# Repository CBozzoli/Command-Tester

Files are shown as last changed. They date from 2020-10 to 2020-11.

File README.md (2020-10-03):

# Command-Tester
Arduino Pro Mini Sketch for the Sacramento Astromech Builders Command Tester

Overview:

The purpose of the Command Tester board is to allow a user to send commands to various devices for testing purposes without having to install those devices into an existing system first.  This makes benchtop testing much easier.

The tester can be powered with a 7-36V input to the onboard Pololu D24V50F5 regulator which will give a constant 5V output at 5A to power the connected devices over the Serial or I2C bus.  There is also a +5V output header to power additional devices if needed.  Alternately, this header can be used to feed a regulated 5V input to the board if the user does not wish to install the Pololu regulator.

The Command Tester supports sending commands via I2C as well as Serial. Under normal usage, the command tester does not need to receive I2C commands, however there is receive code in the basic sketch, so it is possible to send I2C commands to the tester if the user wishes it. See the Code section below for more information on this. At this time, the tester does not receive Serial commands.

Board Versions:

There are currently 3 versions of the Command Tester board.  The differences between the boards are:

•	The v1 board has 15 command buttons, while v1.1 and v1.2 have 14. The reason for this is because Digital pin 13 is connected to the LED on the Arduino Pro Mini and should not be used as an input, therefore it was removed in the later versions. If you are using a v1 board, you should skip the CMD 12 button when assembling (this means that CMD 13- 15 are actually CMD 12-14). The code already takes this into account.

•	The location of the Shift Switch and LED is different on each version of the board.
Other than the above, the boards are functionally equivalent.

The Arduino Pins are assigned as follows:

•	TX0		Serial Transmit

•	RXI		Serial Receive

•	D2		Command 1

•	D3		Command 2

•	D4		Command 3

•	D5		Command 4

•	D6		Command 5

•	D7		Command 6

•	D8		Command 7

•	D9		Command 8

•	D10		Command 9

•	D11		Command 10

•	D12		Command 11

•	D13		Pro Mini On Board LED

•	A0/D14	Command 12

•	A1/D15	Command 13

•	A2/D16	Command 14

•	A3/D17	Shift

•	A4/D18	SDA (I2C)

•	A5/D19	SCL (I2C)		

Code:

The current version of the Command Tester code consists of two files that must be placed in the same directory:

•	Command_Tester_Skeleton_1.1.ino (the main sketch)

•	config.h (header file that includes configuration settings)

The sketch is distributed as a “skeleton” to allow users to insert the commands needed for the devices they are testing.  This is done by typing the commands into the arrays on the config.h tab.  Notes on how to do this are in the sketch.

There are several user configurable settings in the config header:

•	Commands

•	BAUD Rate (Default is 2400 for Teeces compatibility, 9600 and 57600 are also available for JEDI and Stealth compatibility)

•	I2C Address of the Tester (default is 0)

•	I2C Addresses for receive devices

•	Debug Toggle (turns on/off debug messages, default is on)

•	I2C Receive Mode (see below for more on this)

The default behavior of the Command Tester is as the I2C bus master and does not need to receive I2C commands; however, the receive code is included in case a scenario arises where it is needed. The receive command function is different depending on what device is sending the I2C commands. For example, the Stealth Controller sends integer I2C commands only, but the Marcduino sends commands as character strings. To deal with this, a software switch called SIMPLE_I2C is included to determine the I2C Receive Mode. If the device sending the commands to the tester is something like the Stealth Controller, then turn on Simple receive by uncommenting this line in the config header. If it is something like the Marcduino, then use the complex receive. A general rule of thumb to help you determine which to use is how you enter the commands in the sketch that is sending them. If you must put the command in quotes (e.g. “10\r”), then use complex. If you do not use quotes (e.g. 10), use simple. The default setting is complex.

Warning:  If you do find a need for the tester to receive commands, you may need to do additional coding to accomplish what you need as neither mode will parse JAWALITE commands (both simple and complex modes only handle numerical commands).

Bill of Materials:

•	1x Arduino Pro Mini 5V, 16 MHz

•	1x Pololu D24V50F5 5v, 5A Step-Down Regulator (https://www.pololu.com/product/2851)

•	Various Male and Female Pin Headers

•	14x Momentary Tactile Button Switch (Digikey Part Number 1528-367-ND, https://www.digikey.com/products/en?mpart=367&v=1528)

•	1x 5mm LED

•	1x 1k Ohm Resistor

•	1x Screw Terminal Block (2-Pin, 5 mm Pitch, Side Entry, https://www.pololu.com/product/2440)

•	1x 6-pin, 2.54mm Pitch, Self-Latching Switch (I don’t have a part number for these. I purchased them from Amazon.com in a variety pack and used the 8x8mm ones. If you buy these, you should probably test the switch before soldering it on to make sure the pin configuration is correct. https://www.amazon.com/gp/product/B07J4ZCWNX/ref=ppx_yo_dt_b_asin_title_o03_s00?ie=UTF8&psc=1).
 
Images can be found in the Wiki verion of this file here: https://github.com/CBozzoli/Command-Tester/wiki

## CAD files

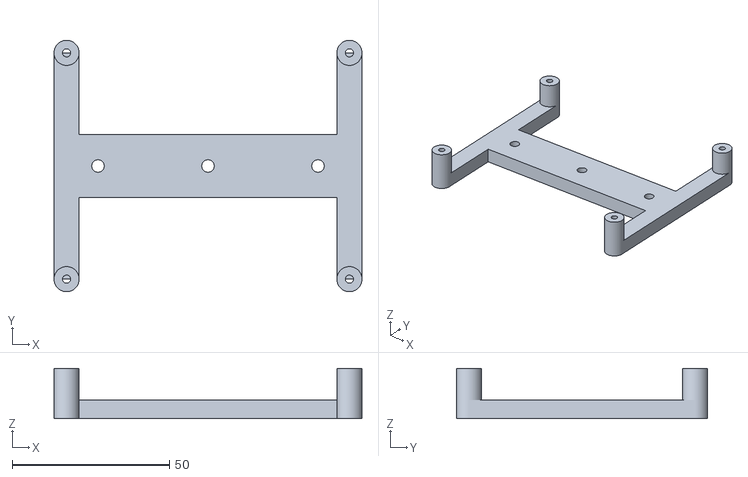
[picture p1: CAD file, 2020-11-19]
Command_Tester_Base.stl
98.0 x 80.0 x 16.0

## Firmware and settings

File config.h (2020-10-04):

// SacAstromech Command Tester v1.1
// Configuration Header

// Place the name of the command set here.  This is used for Debug lines.
// (e.g. "PSI Pro Commands")

#define COMMAND_SET "Test Command Set"

// Enter Command strings here.
// Place the command between the quote marks.
// Format is dependent on the devices you are using
// (e.g. 0T1|10\r for a JAWALITE formatted PSI Pro command with a time modifier)

//Array for Commands 1-14
char *CMD[] {
"" ,     // CMD 1 
"" ,     // CMD 2 
"" ,     // CMD 3 
"" ,     // CMD 4 
"" ,     // CMD 5 
"" ,     // CMD 6 
"" ,     // CMD 7 
"" ,     // CMD 8 
"" ,     // CMD 9 
"" ,     // CMD 10 
"" ,     // CMD 11 
"" ,     // CMD 12 
"" ,     // CMD 13 
"" ,     // CMD 14 
};

//Array for Commands 15-28
char *SHIFT_CMD[] {
"" ,     // SHIFT/CMD 1 
"" ,     // SHIFT/CMD 2 
"" ,     // SHIFT/CMD 3 
"" ,     // SHIFT/CMD 4 
"" ,     // SHIFT/CMD 5 
"" ,     // SHIFT/CMD 6 
"" ,     // SHIFT/CMD 7 
"" ,     // SHIFT/CMD 8 
"" ,     // SHIFT/CMD 9 
"" ,     // SHIFT/CMD 10 
"" ,     // SHIFT/CMD 11 
"" ,     // SHIFT/CMD 12
"" ,     // SHIFT/CMD 13
"" ,     // SHIFT/CMD 14
};

// Baud Rate default is 2400.  Uncomment to switch to 9600 or 57600
//#define _57600BAUDStealth_  //Default BAUD Rate for Stealth Controller systems
//#define _9600BAUDSJEDI_     //Default BAUD Rate for Jedi Controller systems

// incoming I2C command
#define MYI2CADDR 0      //I2C Address for Command Tester

// Destination I2C address (change to match the device you are testing)
#define DEST_I2C 22 //PSI Pro

/* The default behaviour of the Command Tester does not need to receive
*  I2C commands; however, the receive code is included in case a scenario
*  arises where it is needed.
*  The receive command function is different depending on what device
*  is sending the I2C commands. For example, the Stealth Controller sends
*  integer I2C commands only, but the Marcduino sends commands as character
*  strings.
*  The complex example will only handle commands that are numbers.
*  It will not parse JAWALITE commands.
*/

// Uncomment to use basic integer I2C receive handling
//#define SIMPLE_I2C

// Uncomment this if you want Debug output.
// By default debug output is not enabled in
// the release version
#define DEBUG

//Setup Debug Switch
#ifdef DEBUG
  #define DEBUG_PRINT_LN(msg)  Serial.println(msg)
  #define DEBUG_PRINT(msg)  Serial.print(msg)
#else
  #define DEBUG_PRINT_LN(msg)
  #define DEBUG_PRINT(msg)
#endif

//-------------- Nothing Below This Line Should Need to be Changed --------------

//Variables for Read Function
#define INPUTMODE INPUT_PULLUP    // Pin Mode for Command pins: INPUT or INPUT_PULLUP
#define BOUNCETIME 50             // bouncing time in milliseconds

// maximum number of characters in a command (63 chars since we need the null termination)
#define CMD_MAX_LENGTH 64

// memory for command string processing
char cmdString[CMD_MAX_LENGTH];

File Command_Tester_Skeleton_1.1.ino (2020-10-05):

// SacAstromech Command Tester v1.1
// By Chris Bozzoli (DBoz)
// With code contributions from Neil Hutchison (theJugg1er)
// v1.1 Added Debug Switch and I2C Receive Switch. Rewrote Read Function and added do_Command function. Simplified Main Loop. 9/26/20

//User modifiable variables are located on the config.h tab.
//DO NOT MODIFY ANYTHING BELOW THIS LINE

#include <Wire.h>
#include "config.h"

int I2CCommand = 0;

int SHIFT_SW;

//Variables for Read Function
byte buttonPins[] = {2, 3, 4, 5, 6, 7, 8, 9, 10, 11, 12, 14, 15, 16}; // pin numbers for all Command Buttons
#define STATUS_LED  13
#define SHIFT_PIN   17
#define NUMBUTTONS sizeof(buttonPins) // number of buttons (automatically calculated)
byte buttonState[NUMBUTTONS];  // array holds the actual HIGH/LOW states
byte buttonChange[NUMBUTTONS]; // array holds the state changes when button is pressed or released
enum {UNCHANGED, BUTTONUP, BUTTONDOWN};

// ------------------------------------------
void setup() {

  uint16_t baudrate;

#ifdef _57600BAUDStealth_
  baudrate = 57600;
#elif  _9600BAUDSJEDI_
  baudrate = 9600;
#else
  baudrate = 2400;
#endif

  Serial.begin(baudrate); //Begin Serial Bus

  DEBUG_PRINT_LN("SacAstromech Command Tester v1.1 (9-26-20)");
  DEBUG_PRINT_LN(COMMAND_SET);

  DEBUG_PRINT("My i2C Address: ");
  DEBUG_PRINT_LN(MYI2CADDR);

  Wire.begin();  // Start I2C communication Bus as the Master

  Wire.onReceive(receiveEvent); // routine to call/run when we receive a simple I2C command

  for (int i = 0; i < NUMBUTTONS; i++) pinMode(buttonPins[i], INPUTMODE); // Defines mode for Command Button Pins

  pinMode(SHIFT_PIN, INPUT_PULLUP);
  pinMode(STATUS_LED, OUTPUT);

  digitalWrite(STATUS_LED, LOW);

}

//----------------------------------------------------------------------------
//  Delay function
//----------------------------------------------------------------------------
void waitTime(unsigned long waitTime)
{
  unsigned long endTime = millis() + waitTime;
  while (millis() < endTime)
  {}// do nothing
}

//----------------------------------------------------------------------------
//  Blink function
//----------------------------------------------------------------------------

void Blink(byte PIN, byte DELAY_MS, byte loops) {
  for (byte i = 0; i < loops; i++)  {
    digitalWrite(PIN, HIGH);
    waitTime(DELAY_MS);
    digitalWrite(PIN, LOW);
    waitTime(DELAY_MS);
  }
}

//----------------------------------------------------------------------------
//  I2C Command Functions
//----------------------------------------------------------------------------

//Send Event

void sendI2C(uint8_t addr, const char *I2Ccmd, bool CheckSum) {
  byte sum = 0; //stores Checksum for Stealth Receiver
  const char *i;
  i = I2Ccmd;
  Wire.beginTransmission(addr);
  while (*i) {
    Wire.write(*i);
    sum += byte(*i); //Checksum for Stealth Controller
    i++;
  }
  if (CheckSum) {
    Wire.write(sum); //Checksum for Stealth Controller
    DEBUG_PRINT("Checksum: ");
    DEBUG_PRINT_LN(sum);
    Wire.endTransmission();
  }
  else {
    Wire.endTransmission();
  }

  DEBUG_PRINT("Sent I2C Command: ");
  DEBUG_PRINT(I2Ccmd);
  DEBUG_PRINT(" to: ");
  DEBUG_PRINT_LN(addr);
}

//----------------------------------------------------------------------------
/* The default behaviour of the Command Tester does not need to receive
   I2C commands; however, the receive code is included in case a scenario
   arises where it is needed.
   The receive command function is different depending on what device
   is sending the I2C commands. For example, the Stealth Controller sends
   integer I2C commands only, but the Marcduino sends commands as character
   strings.  You can define which receive event to use on the config.h tab.
   The complex example will only handle commands that are numbers.
   It will not parse JAWALITE commands.
*/

void receiveEvent(int eventCode) {

#ifdef SIMPLE_I2C
  //Receive event for Integer commands only as come from the Stealth Controller)

#define I2C_REC_MODE "Simple"

  I2CCommand = Wire.read();

  DEBUG_PRINT("Received I2C Command Code: ");
  DEBUG_PRINT_LN(I2CCommand);

#else
  // Receive event for complex commands made up of strings.
  // The command line builder is needed along with this function.
  // Will not parse JAWALITE commands.

#define I2C_REC_MODE "Complex"

  while (Wire.available()) {

    bool command_available;
    char ch = (char)Wire.read();

    DEBUG_PRINT("I2C Character received ");
    DEBUG_PRINT_LN(ch);

    command_available = buildCommand(ch, cmdString); // build command line

    if (command_available)
    {
      I2CCommand = atoi(cmdString); // Converts the command line from ASCII to an Integer

      DEBUG_PRINT("Received Command String: ");
      DEBUG_PRINT_LN(cmdString);

      DEBUG_PRINT("Received I2C Command Code: ");
      DEBUG_PRINT_LN(I2CCommand);
    }
  }

#endif

  DEBUG_PRINT("I2C Receive Mode: ");
  DEBUG_PRINT_LN(I2C_REC_MODE);

}

// Receive event command line builder, makes a valid command line from the input

byte buildCommand(char ch, char* output_str)
{
  static uint8_t pos = 0;
  switch (ch)
  {
    case '\r':                          // end character recognized
      output_str[pos] = '\0'; // append the end of string character
      pos = 0;      // reset buffer pointer
      return true;      // return and signal command ready
      break;
    default:        // regular character
      output_str[pos] = ch; // append the  character to the command string
      if (pos <= CMD_MAX_LENGTH - 1)pos++; // too many characters, discard them.
      break;
  }
  return false;
}

//----------------------------------------------------------------------------
//  Button Read/Debounce function
//----------------------------------------------------------------------------

void Read() { // read the input state and state changes of all Command Buttons

  static unsigned long lastButtonTime; // time stamp for remembering the time when the button states were last read
  memset(buttonChange, 0, sizeof(buttonChange)); // reset all old state changes

  if (millis() - lastButtonTime < BOUNCETIME)
    return; // within bounce time: leave the function

  lastButtonTime = millis(); // remember the current time

  for (int i = 0; i < NUMBUTTONS; i++) {
    byte curState = digitalRead(buttonPins[i]);      // current button state


    if (INPUTMODE == INPUT_PULLUP) curState = !curState; // logic is inverted with INPUT_PULLUP

    if (curState != buttonState[i]) {                 // state change detected

      if (curState == HIGH) buttonChange[i] = BUTTONDOWN;

      else buttonChange[i] = BUTTONUP;
    }

    buttonState[i] = curState; // save the current button state
  }
}

//----------------------------------------------------------------------------
//  Execute Command Function
//----------------------------------------------------------------------------
void do_Command() {

  for (int i = 0; i < NUMBUTTONS; i++) {

    if ((buttonChange[i]) == BUTTONDOWN) {

      SHIFT_SW = digitalRead(SHIFT_PIN);

      if (SHIFT_SW == HIGH) { //For Commands 1-14
        sendI2C(DEST_I2C, CMD[i], false);
        Serial.print(CMD[i]);
        Blink(STATUS_LED, 500, 2);
      }
      else { //For Commands 15-28
        sendI2C(DEST_I2C, SHIFT_CMD[i], false);
        Serial.print(SHIFT_CMD[i]);
        Blink(STATUS_LED, 500, 3);
      }
    }
  }
}

//-----------------------------------------------------
// Main Loop
//-----------------------------------------------------

void loop() {

  Read(); // Read the Command Pins

  do_Command(); // Do commands for any buttons that have been pressed
}
